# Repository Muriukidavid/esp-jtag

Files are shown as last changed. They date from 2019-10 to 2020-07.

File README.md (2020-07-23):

This is a JTAG programmer for esp targets based on esp-prog redone in Kicad.

The goal of this repo is to enable customization by adding or removing features. Feel welcome to fork the repo and share back your customizations through a pull request.

### Features:
* FT2232H based
* Esp Jtag programming
* A separate serial port for debug
* SN74AH buffers for JTAG IO pins(5V/3V torelant)
* Rx/Tx status LEDs
* Autoprogram using RTS and DTS signals

### TODO
* <s>Layout the PCB and route</s>
- <s>Add LCSC.com BOM column</s> 
* Add digikey BOM column
<br/>

### Schematic
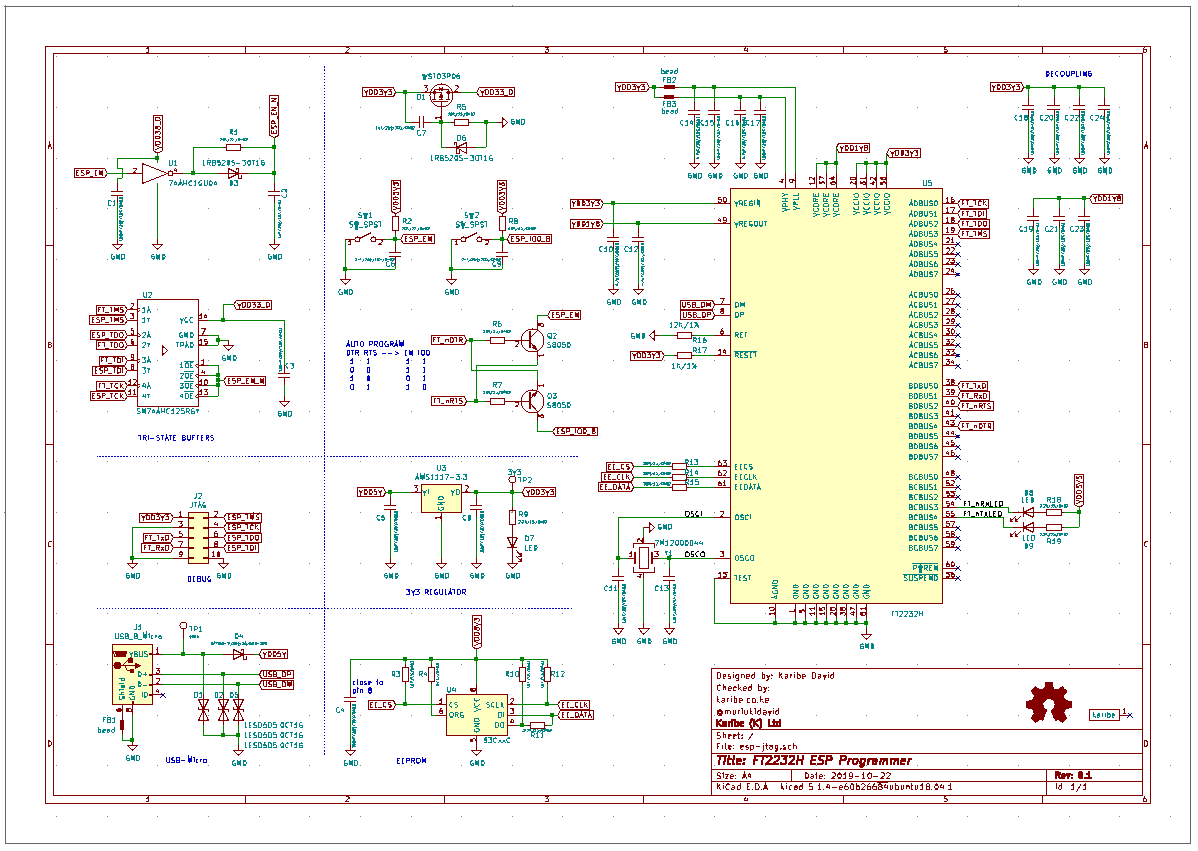
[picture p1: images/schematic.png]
The schematic


### Board 3D Top View 

A preview of the on-going PCB layout design
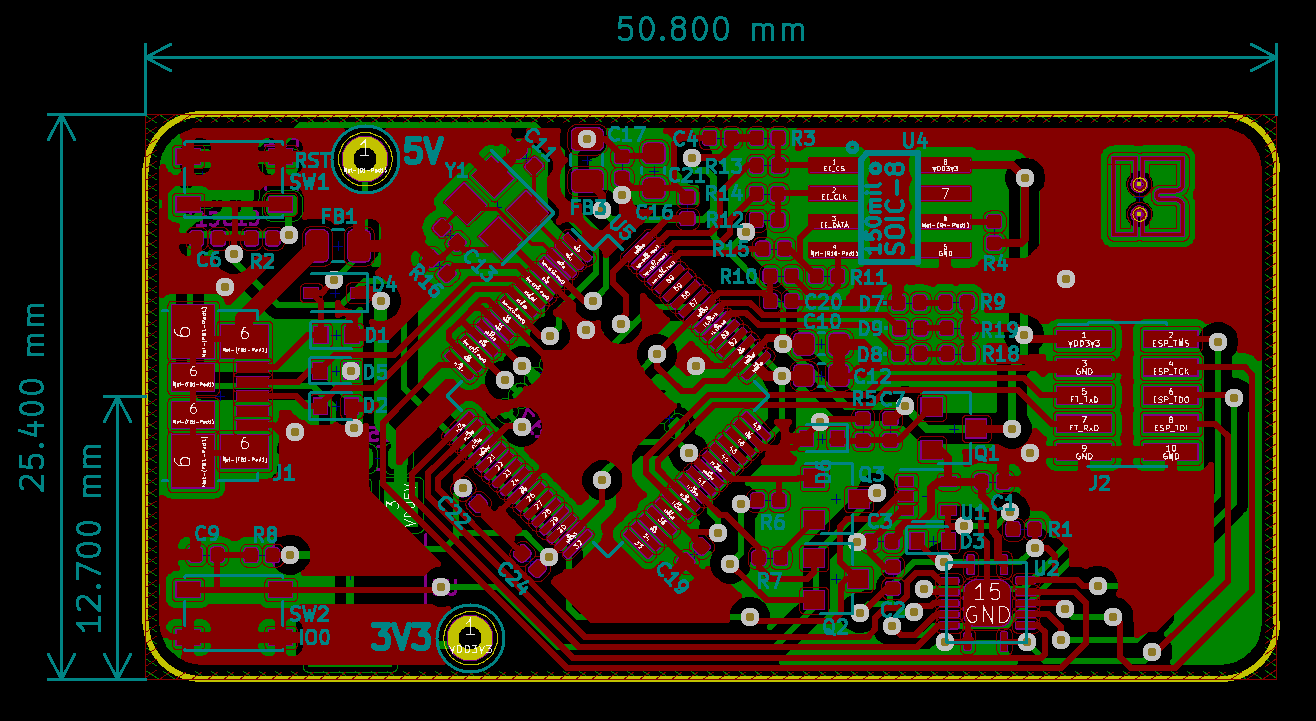
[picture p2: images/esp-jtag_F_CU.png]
Board top copper


3D TOP view 
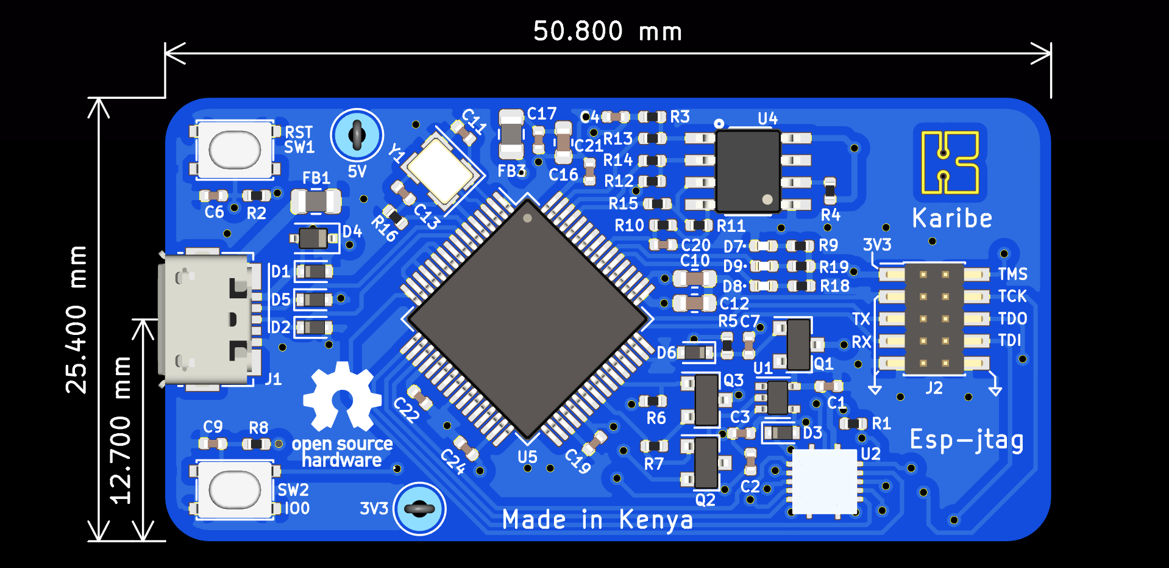
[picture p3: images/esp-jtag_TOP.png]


3D ISO view 
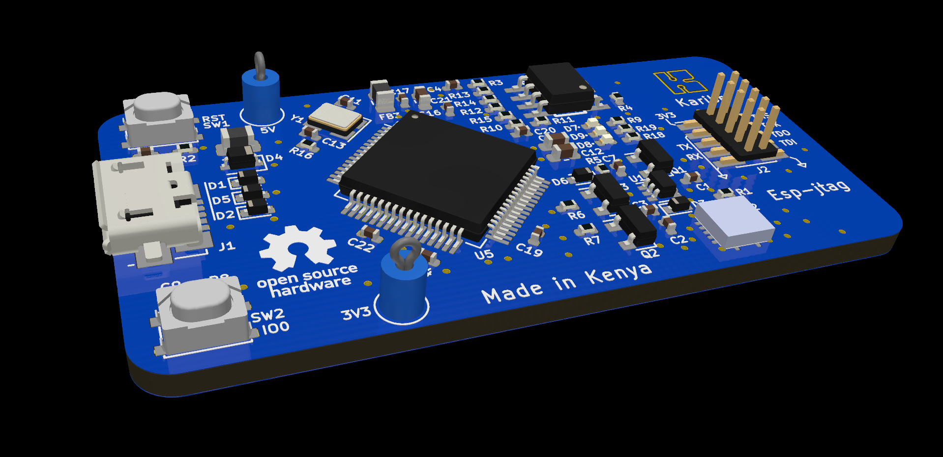
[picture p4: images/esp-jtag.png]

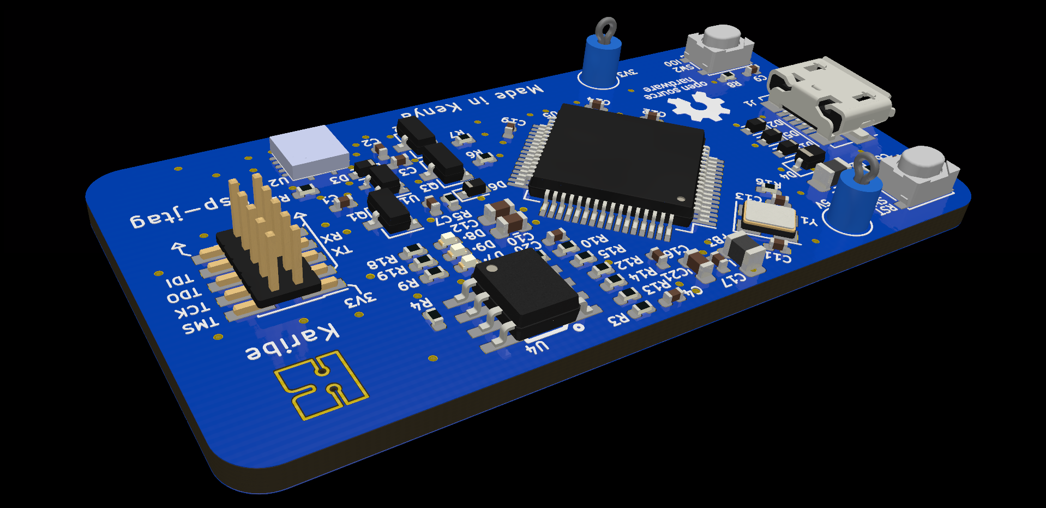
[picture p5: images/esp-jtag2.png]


### BOM
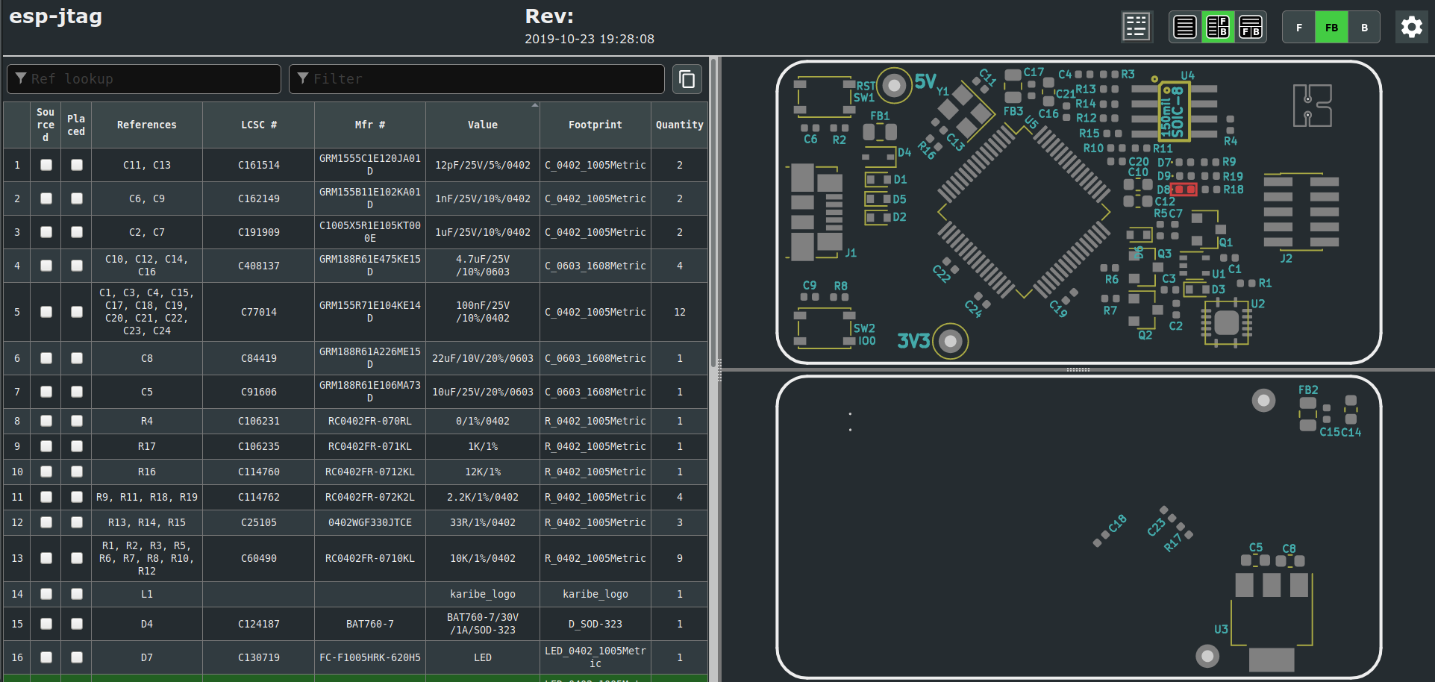
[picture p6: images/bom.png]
BOM
<a href="bom/ibom.html" rel="BOM">

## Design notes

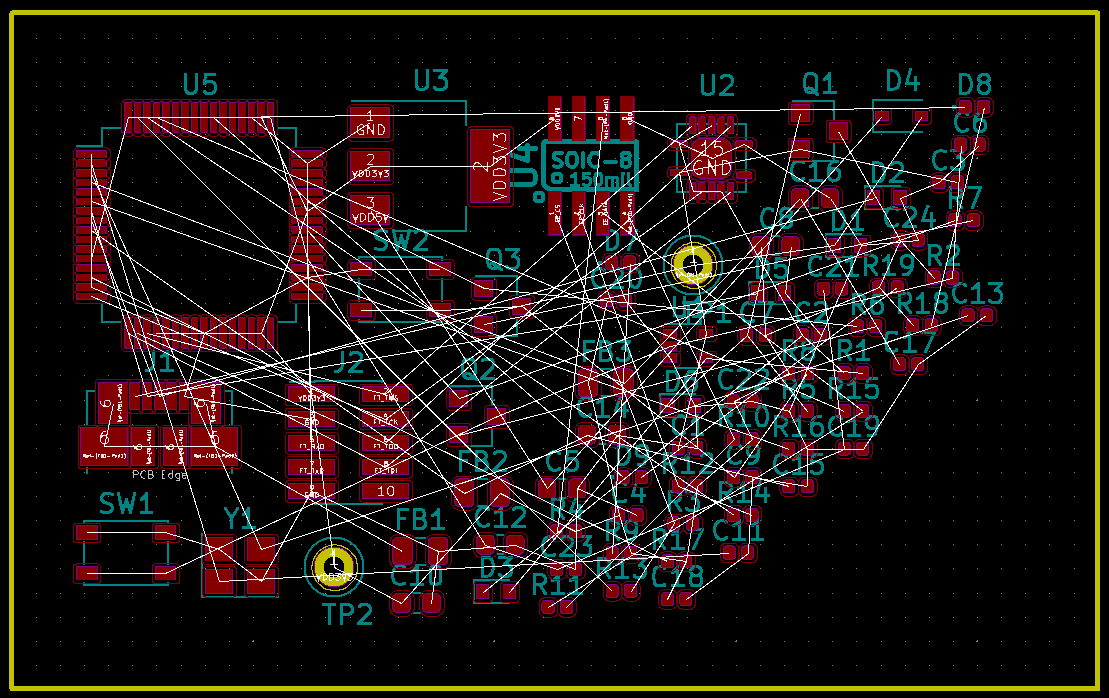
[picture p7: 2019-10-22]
images/layout.png

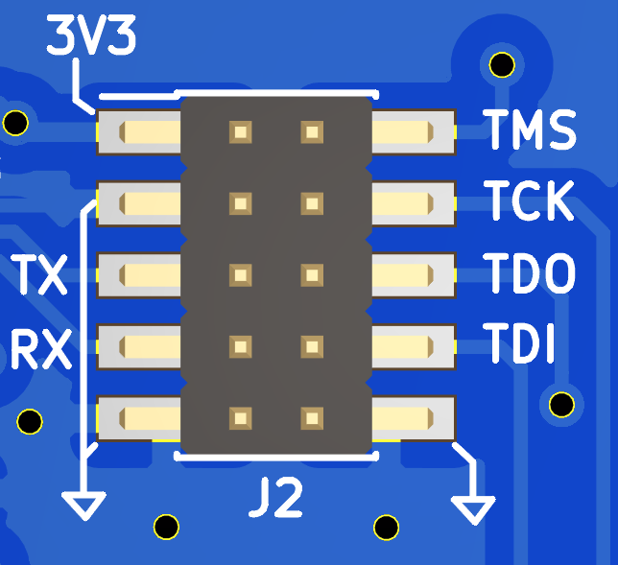
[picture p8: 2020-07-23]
images/jtag_connector.png

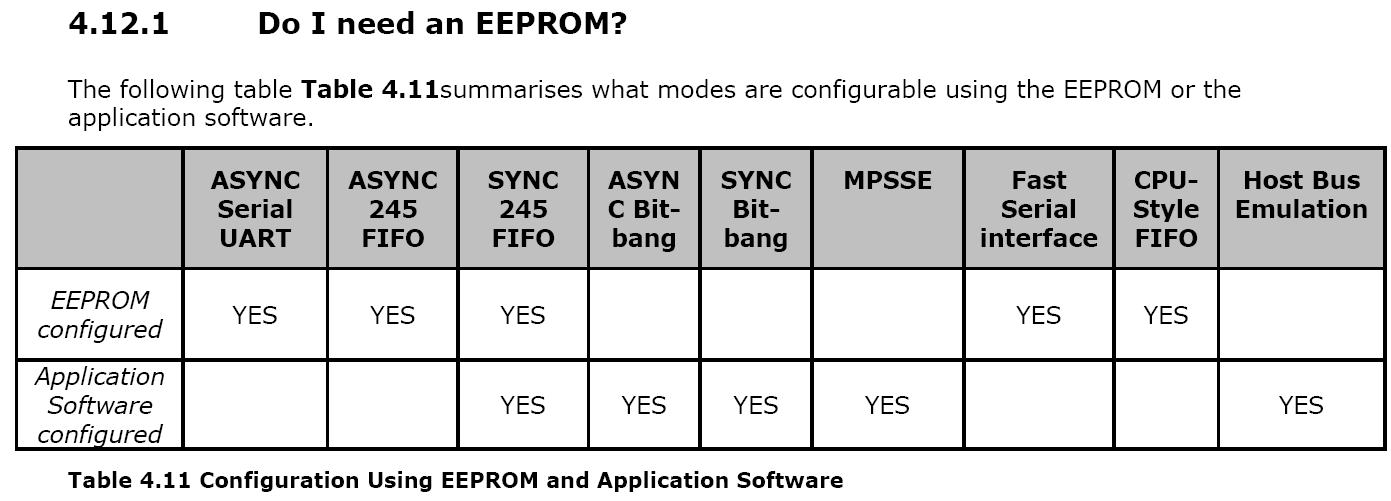
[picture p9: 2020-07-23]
images/ft2232H-eeprom.png

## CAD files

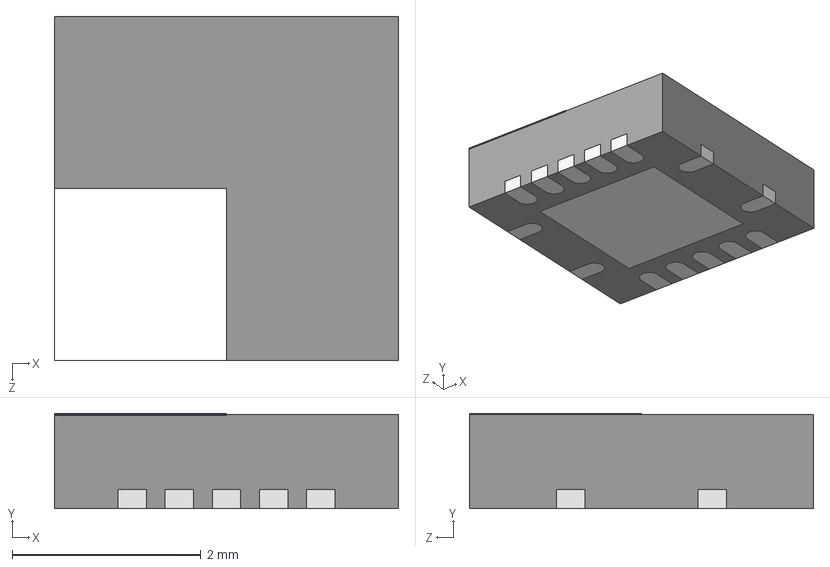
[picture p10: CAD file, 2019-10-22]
3Dmodels/SN74AHC04RGYR.step
3.65 x 1.01 x 3.65 mm

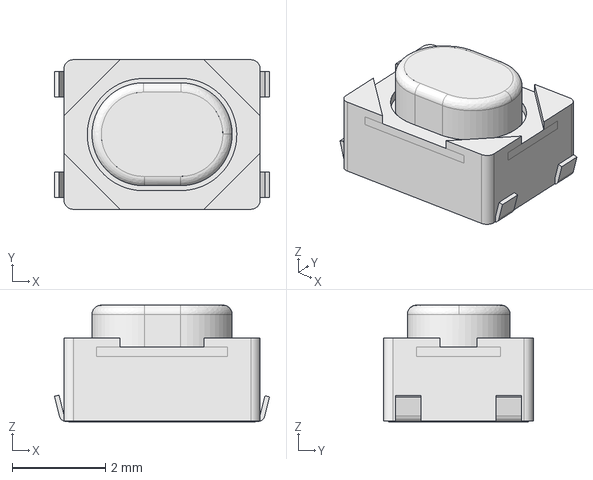
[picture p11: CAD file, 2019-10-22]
3Dmodels/PTS810.step
4.60 x 3.20 x 2.50 mm

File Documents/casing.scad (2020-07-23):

/* 
Parameters 
*/
//Global resolution angle
$fa = .3;
//Global resolution side
$fs = .3;

//Width of the casing
width = 50.8;
//Breadth of the casing
breadth = 25.4;
//Height of the casing
height = 5;
//wall thickness
wallThickness = 2;
//allowance around the inside of the casing
allowance = 0.2;

/* Renders*/
base(width, breadth, height, wallThickness);

/* Modules */
//create outer shell
module base(shellWidth, shellBreadth, shellHeight, shellThickness){
    difference(){
    union(){
    difference(){
        cube([width+2*shellThickness, breadth+2*shellThickness, shellHeight+shellThickness], center = true);
        translate([0,0,(shellThickness/2)+1])
        cube([shellWidth, shellBreadth, shellHeight], center = true);
    }
    translate([shellWidth/2-shellHeight/2,shellBreadth/2-shellHeight/2,shellThickness])
    #cube([shellHeight/2, shellHeight/2,shellHeight], center=true);
    }
    translate([shellWidth/2-shellHeight/2,shellBreadth/2-shellHeight/2,shellThickness])
    cylinder(d=shellHeight, h=shellHeight, center=true);
    }
}

module cover(){
    
}

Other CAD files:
3Dmodels/SN74AHC04RGYR.igs

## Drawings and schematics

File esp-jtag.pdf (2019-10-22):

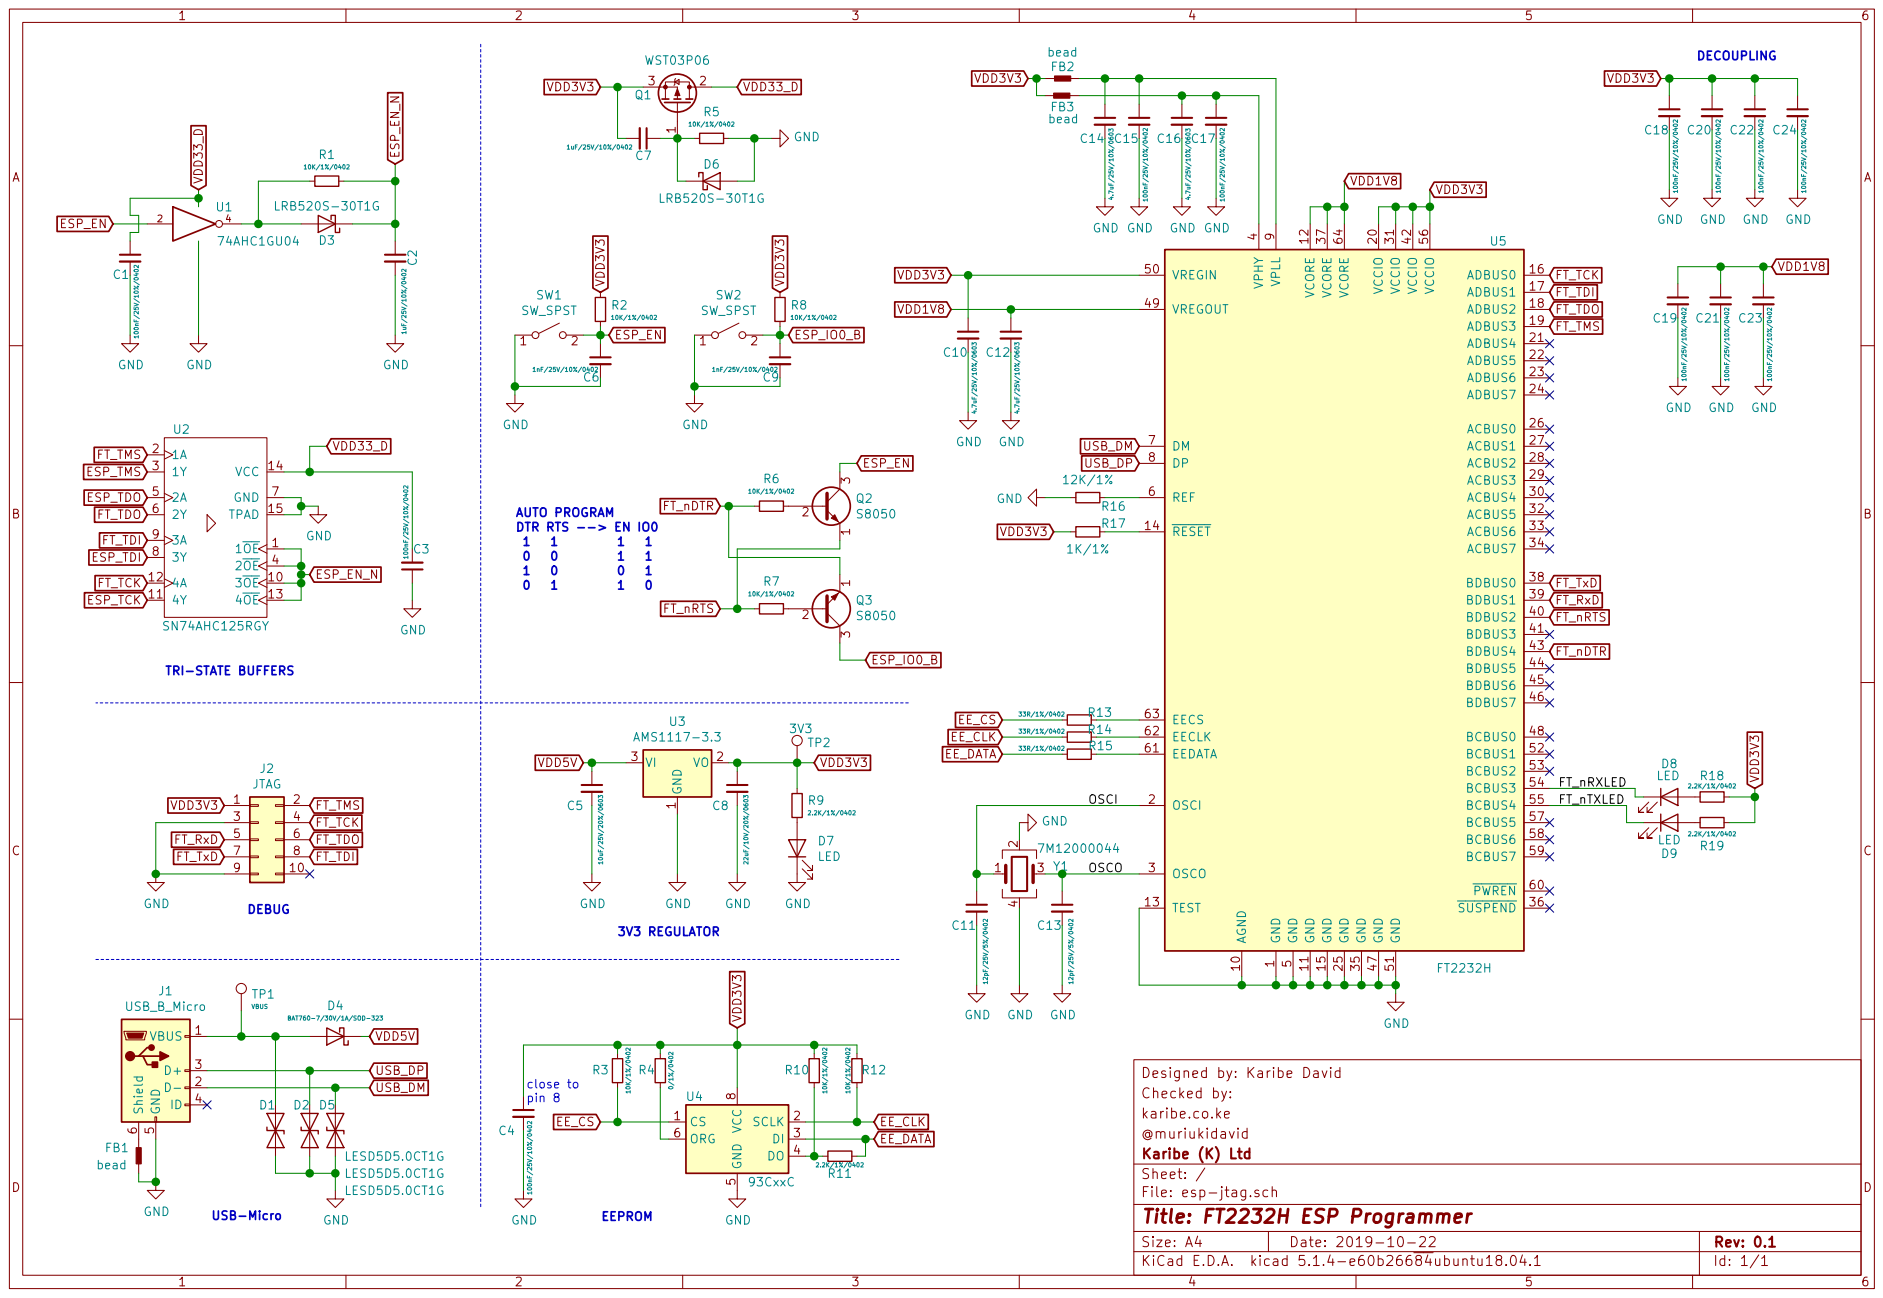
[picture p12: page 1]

1 AGND 10 GND 11 VCORE 12 TEST 13 RESET 14 GND 15 ADBUS0 16 ADBUS1 17 ADBUS2 18 ADBUS3 19 OSCI 2 VCCIO 20 ADBUS4 21 ADBUS5 22 ADBUS6 23 ADBUS7 24 GND 25 ACBUS0 26 ACBUS1 27 ACBUS2 28 ACBUS3 29 OSCO 3 ACBUS4 30 VCCIO 31 ACBUS5 32 ACBUS6 33 ACBUS7 34 GND 35 SUSPEND 36 VCORE 37 BDBUS0 38 BDBUS1 39 VPHY

4 BDBUS2 40 BDBUS3 41 VCCIO 42 BDBUS4 43 BDBUS5 44 BDBUS6 45 BDBUS7 46 GND 47 BCBUS0 48 VREGOUT 49 GND

5 VREGIN 50 GND 51 BCBUS1 52 BCBUS2 53 BCBUS3 54 BCBUS4 55 VCCIO 56 BCBUS5 57 BCBUS6 58 BCBUS7 59 REF 6 PWREN 60 EEDATA 61 EECLK 62 EECS 63 VCORE 64 DM 7 DP 8 VPLL

Designed by: Karibe David
karibe.co.ke Checked by:

@muriukidavid
File: esp-jtag.sch Sheet: / Karibe (K) Ltd

Id: 1/1 Title: FT2232H ESP Programmer

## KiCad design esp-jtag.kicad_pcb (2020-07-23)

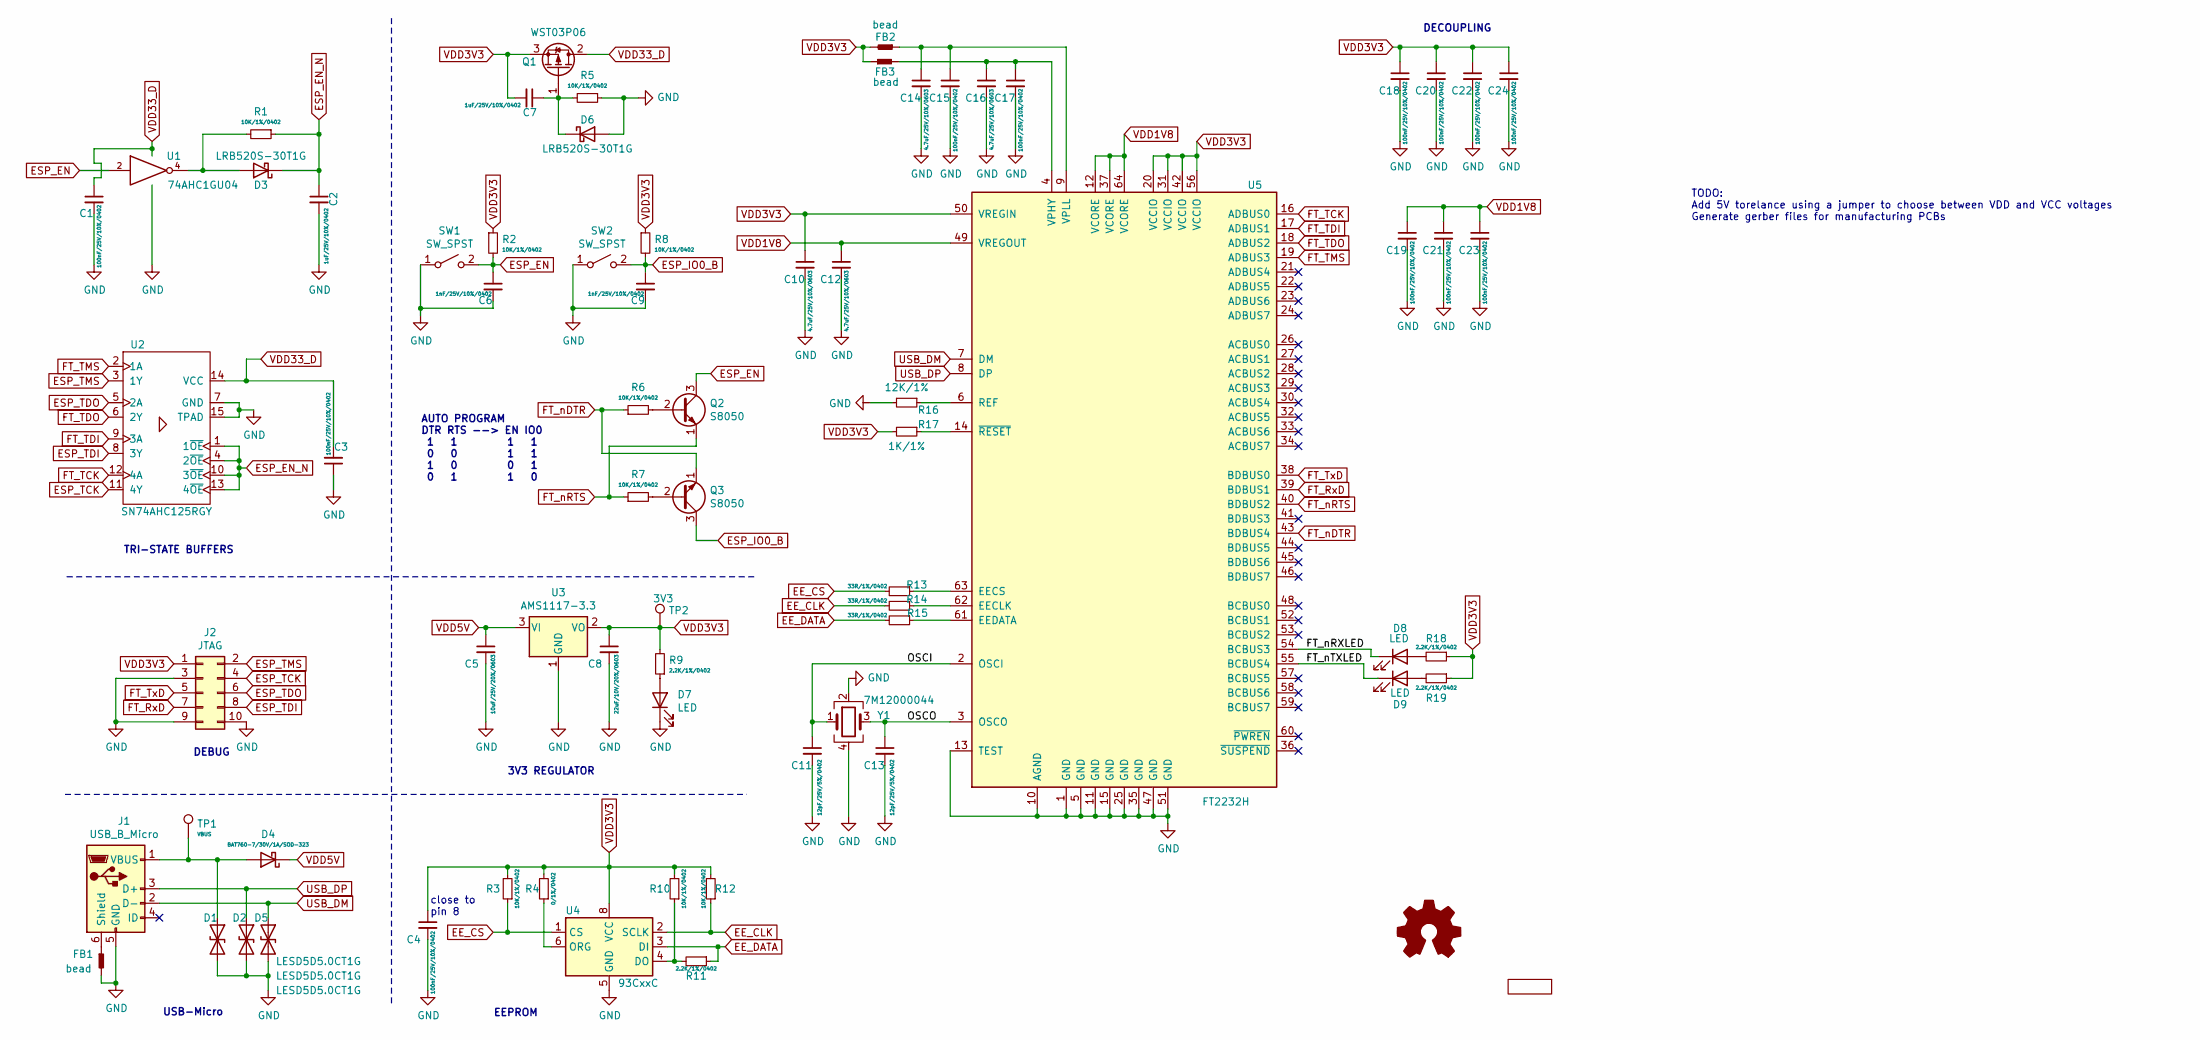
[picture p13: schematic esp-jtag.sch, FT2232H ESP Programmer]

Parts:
C1, C3, C4, C15, C17, C18, C19, C20, C21, C22, C23, C24: 100nF/25V/10%/0402; C_0402_1005Metric; Mfr # GRM155R71E104KE14D; LCSC # C77014
C2, C7: 1uF/25V/10%/0402; C_0402_1005Metric; Mfr # C1005X5R1E105KT000E; LCSC # C191909
C5: 10uF/25V/20%/0603; C_0603_1608Metric; Mfr # GRM188R61E106MA73D; LCSC # C91606
C6, C9: 1nF/25V/10%/0402; C_0402_1005Metric; Mfr # GRM155B11E102KA01D; LCSC # C162149
C8: 22uF/10V/20%/0603; C_0603_1608Metric; Mfr # GRM188R61A226ME15D; LCSC # C84419
C10, C12, C14, C16: 4.7uF/25V/10%/0603; C_0603_1608Metric; Mfr # GRM188R61E475KE15D; LCSC # C408137
C11, C13: 12pF/25V/5%/0402; C_0402_1005Metric; Mfr # GRM1555C1E120JA01D; LCSC # C161514
D1, D2, D5: LESD5D5.0CT1G; D_SOD-523; Mfr # LESD5D5.0CT1G; LCSC # C383211
D3, D6: LRB520S-30T1G; D_SOD-523; Mfr # LRB520S-30T1G; LCSC # C83680
D4: BAT760-7/30V/1A/SOD-323; D_SOD-323; Mfr # BAT760-7; LCSC # C124187
D7: LED; LED_0402_1005Metric; Mfr # FC-F1005HRK-620H5; LCSC # C130719
D8: LED; LED_0402_1005Metric; Mfr # BL-HB337A-AV-TRB; LCSC # C165977
D9: LED; LED_0402_1005Metric; Mfr # BL-HGE37A-AV-TRB; LCSC # C165979
FB1, FB2, FB3: bead; L_0805_2012Metric; Mfr # BLM21AG601SN1D; LCSC # C85837
J1: USB_B_Micro; USB_Micro-B_Molex_47346-0001; Mfr # 47346-0001; LCSC # C132560
J2: JTAG; PinHeader_2x05_P1.27mm_Vertical_SMD
L1: karibe_logo
Q1: WST03P06; SOT-23; Mfr # WST03P06; LCSC # C105166
Q2, Q3: S8050; SOT-23; Mfr # S8050; LCSC # C2146
R1, R2, R3, R5, R6, R7, R8, R10, R12: 10K/1%/0402; R_0402_1005Metric; Mfr # RC0402FR-0710KL; LCSC # C60490
R4: 0/1%/0402; R_0402_1005Metric; Mfr # RC0402FR-070RL; LCSC # C106231
R9, R11, R18, R19: 2.2K/1%/0402; R_0402_1005Metric; Mfr # RC0402FR-072K2L; LCSC # C114762
R13, R14, R15: 33R/1%/0402; R_0402_1005Metric; Mfr # 0402WGF330JTCE; LCSC # C25105
R16: 12K/1%; R_0402_1005Metric; Mfr # RC0402FR-0712KL; LCSC # C114760
R17: 1K/1%; R_0402_1005Metric; Mfr # RC0402FR-071KL; LCSC # C106235
SW1, SW2: SW_SPST; SW_SPST_PTS810; Mfr # PTS810SJG250SMTRLFS; LCSC # C221895
TP1: VBUS; TestPoint_Loop_D1.80mm_Drill1.0mm_Beaded; Mfr # 5001; LCSC # C238122
TP2: 3V3; TestPoint_Loop_D1.80mm_Drill1.0mm_Beaded; Mfr # 5001; LCSC # C238122
U1: 74AHC1GU04; SOT-353_SC-70-5; Mfr # 74AHC1GU04GW,125; LCSC # C5514
U2: SN74AHC125RGY; VQFN-14_3.6x3.6x05P; Mfr # SN74AHC125RGY; LCSC # C181604
U3: AMS1117-3.3; SOT-223-3_TabPin2; Mfr # AMS1117-3.3; LCSC # C6186
U4: 93CxxC; SOIC-8_150mil; Mfr # M93C46-WMN6TP; LCSC # C7565
U5: FT2232H; LQFP-64_10x10mm_P0.5mm; Mfr # FT2232HL-REEL; LCSC # C27882
Y1: 7M12000044; Crystal_SMD_3225-4Pin_3.2x2.5mm; Mfr # 7M12000044; LCSC # C93114

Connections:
/FT_nRXLED: D8.1 (K), U5.54 (BCBUS3)
/FT_nTXLED: D9.1 (K), U5.55 (BCBUS4)
/OSCI: C11.1, U5.2 (OSCI), Y1.1
/OSCO: C13.1, U5.3 (OSCO), Y1.3
EE_CLK: R12.1, R14.2, U4.2 (SCLK)
EE_CS: R3.1, R13.2, U4.1 (CS)
EE_DATA: R11.1, R15.2, U4.3 (DI)
ESP_EN: C6.1, Q2.3 (C), R2.2, SW1.2 (B), U1.2
ESP_EN_N: C2.1, D3.1 (K), R1.1, U2.1 (1~OE), U2.4 (2~OE), U2.10 (3~OE), U2.13 (4~OE)
ESP_IO0_B: C9.1, Q3.3 (C), R8.2, SW2.2 (B)
ESP_TCK: J2.4, U2.11 (4Y)
ESP_TDI: J2.8, U2.8 (3Y)
ESP_TDO: J2.6, U2.5 (2A)
ESP_TMS: J2.2, U2.3 (1Y)
FT_RxD: J2.7, U5.39 (BDBUS1)
FT_TCK: U2.12 (4A), U5.16 (ADBUS0)
FT_TDI: U2.9 (3A), U5.17 (ADBUS1)
FT_TDO: U2.6 (2Y), U5.18 (ADBUS2)
FT_TMS: U2.2 (1A), U5.19 (ADBUS3)
FT_TxD: J2.5, U5.38 (BDBUS0)
FT_nDTR: Q3.1 (E), R6.1, U5.43 (BDBUS4)
FT_nRTS: Q2.1 (E), R7.1, U5.40 (BDBUS2)
GND: C1.2, C2.2, C3.1, C4.2, C5.2, C6.2, C8.2, C9.2, C10.2, C11.2, C12.2, C13.2, C14.2, C15.2, C16.2, C17.2, C18.2, C19.2, C20.2, C21.2, C22.2, C23.2, C24.2, D1.2 (A2), D2.2 (A2), D5.2 (A2), D6.2 (A), D7.1 (K), FB1.2, J1.5 (GND), J2.3, J2.9, J2.10, R5.1, R16.2, SW1.1 (A), SW2.1 (A), U1.3 (GND), U2.7 (GND), U2.15 (TPAD), U3.1 (GND), U4.5 (GND), U5.1 (GND), U5.5 (GND), U5.10 (AGND), U5.11 (GND), U5.13 (TEST), U5.15 (GND), U5.25 (GND), U5.35 (GND), U5.47 (GND), U5.51 (GND), Y1.2, Y1.4
unnamed: C7.1, D6.1 (K), Q1.1 (G), R5.2
unnamed: C14.1, C15.1, FB2.1, U5.9 (VPLL)
unnamed: C16.1, C17.1, FB3.2, U5.4 (VPHY)
unnamed: D1.1 (A1), D4.2 (A), J1.1 (VBUS), TP1.1
unnamed: D3.2 (A), R1.2, U1.4
unnamed: D7.2 (A), R9.1
unnamed: D8.2 (A), R18.2
unnamed: D9.2 (A), R19.2
unnamed: FB1.1, J1.6 (Shield)
unnamed: Q2.2 (B), R6.2
unnamed: Q3.2 (B), R7.2
unnamed: R4.1, U4.6 (ORG)
unnamed: R10.1, R11.2, U4.4 (DO)
unnamed: R13.1, U5.63 (EECS)
unnamed: R14.1, U5.62 (EECLK)
unnamed: R15.1, U5.61 (EEDATA)
unnamed: R16.1, U5.6 (REF)
unnamed: R17.1, U5.14 (~RESET)
USB_DM: D5.1 (A1), J1.2 (D-), U5.7 (DM)
USB_DP: D2.1 (A1), J1.3 (D+), U5.8 (DP)
VDD1V8: C12.1, C19.1, C21.1, C23.1, U5.12 (VCORE), U5.37 (VCORE), U5.49 (VREGOUT), U5.64 (VCORE)
VDD3V3: C4.1, C7.2, C8.1, C10.1, C18.1, C20.1, C22.1, C24.1, FB2.2, FB3.1, J2.1, Q1.3 (S), R2.1, R3.2, R4.2, R8.1, R9.2, R10.2, R12.2, R17.2, R18.1, R19.1, TP2.1, U3.2 (VO), U4.8 (VCC), U5.20 (VCCIO), U5.31 (VCCIO), U5.42 (VCCIO), U5.50 (VREGIN), U5.56 (VCCIO)
VDD5V: C5.1, D4.1 (K), U3.3 (VI)
VDD33_D: C1.1, C3.2, Q1.2 (D), U1.5 (VCC), U2.14 (VCC)

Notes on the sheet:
close to pin 8
EEPROM
USB-Micro
3V3 REGULATOR
DECOUPLING
DEBUG
TRI-STATE BUFFERS
AUTO PROGRAM DTR RTS --> EN IO0 1 1 1 1 0 0 1 1 1 0 0 1 0 1 1 0
TODO: Add 5V torelance using a jumper to choose between VDD and VCC voltages Generate gerber files for manufacturing PCBs

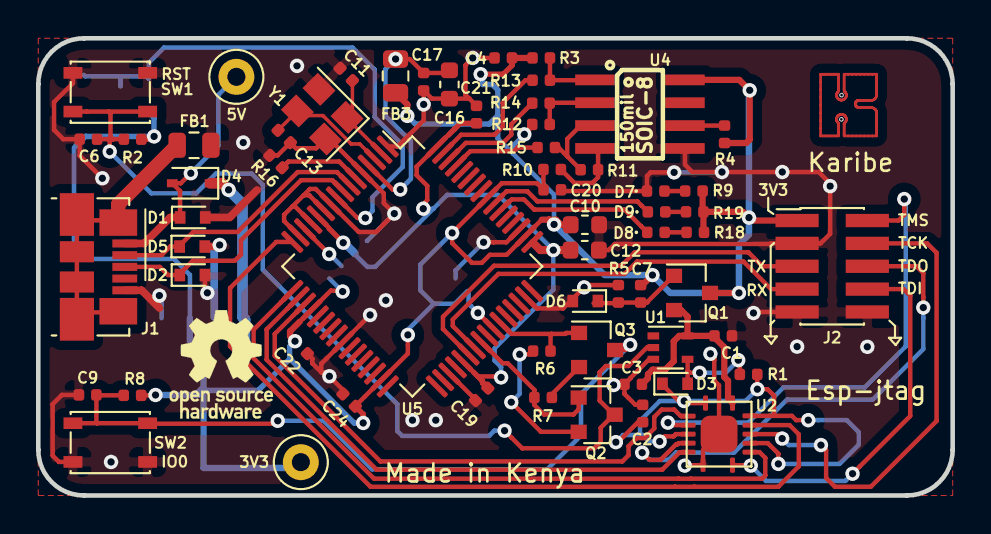
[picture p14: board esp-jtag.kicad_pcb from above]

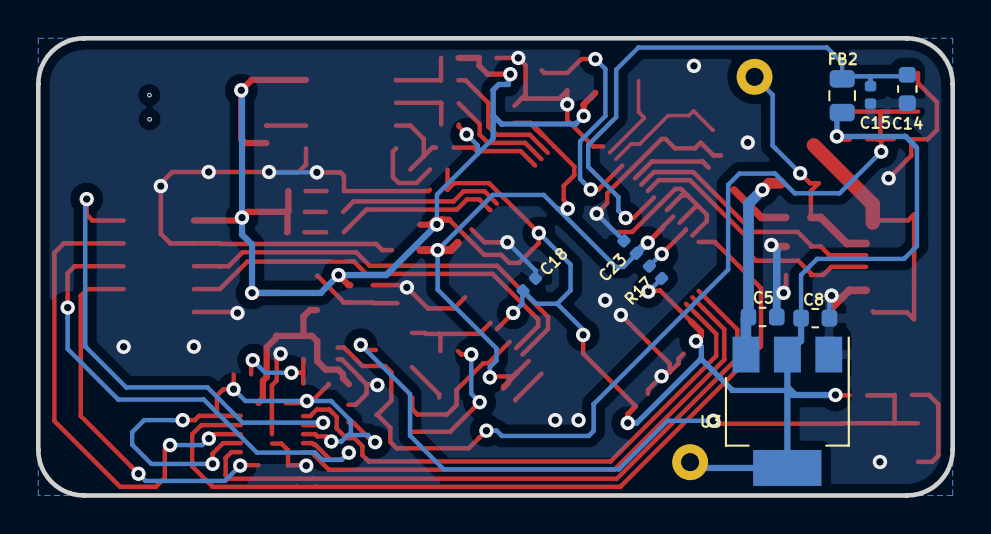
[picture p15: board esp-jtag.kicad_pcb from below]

Board: 2 copper layers, 50.8 x 25.4 mm, 71 parts (9 on the bottom side), 47 nets.

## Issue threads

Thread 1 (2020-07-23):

SPI Flash

pineappletikka, 2020-07-23:
Hi,
I was wondering where is the content of the SPIFlash how to to compile it.
Thanks

Muriukidavid, 2020-07-23:
Hi @pineappletikka thanks for your interest in this, I have not even built this board. The external memory is for storing configurations in order for the FT2232H to be set to operate in different modes, as far as I know. As to how to write to it, I haven't looked into it. I will update these details when I make this board.

Muriukidavid, 2020-07-23:
In case you need more information, check the [datasheet](datasheet https://www.ftdichip.com/Support/Documents/DataSheets/ICs/DS_FT2232H.pdf) page 46.

Muriukidavid, 2020-07-23:
The [FT_Prog](https://www.ftdichip.com/Support/Utilities.htm#FT_PROG) utility is used to write to the external memory

pineappletikka, 2020-07-24:
Hi @Muriukidavid, thanks for the prompt reply!
I will definitely have a look at those documentations.
Good luck with the manufacturing and keep us up to date! :)

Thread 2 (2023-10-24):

Q2 and Q3 (S8050) base and emitter flipped

kJoba, 2023-10-24:
The transistors Q2 and Q3 https://datasheet.lcsc.com/lcsc/1810161230_Jiangsu-Changjing-Electronics-Technology-Co---Ltd--S8050-J3Y_C2146.pdf have their base on pin 1 and emitter on pin2. This seems to be flipped in the schematic.
As a result the automatic toggling of RST and GPIO0 for UART flashing of firmware won't work correctly.

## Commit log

2019-10-22 Add initial revision
    Create a kicad project for the programmer
    Capture a schematic based on esp-prog schematic
    Add manufacturer part number and LCSC part number to all components in the schematic
    Associate all components with correct(hopefully) footprints
    Add missing/custom footprints and 3D models
    export a HTML BOM
    Create initial PCB layout with edge cut polygon and load all the components
    Add a README for the repo
    Add a Documents folder with esp-prog schematic PDF
    Export some images into the images folder, link them in the README
    [PTS810.step, SN74AHC04RGYR.igs, SN74AHC04RGYR.step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]
2019-10-23 Layout and route the PCB
    Prepare the PCB layout by arranging the components
    Route all traces and rectify mistakes in the connections
    Add ground pours on top and bottom copper
    Update the preview images and the README file
    [esp-jtag.kicad_pcb, esp-jtag.sch]
2020-07-23 Minor tweaks
    Finalize PCB layout, especially top silkscreen
    Export ray-tracing renders
    Update the README file
    [casing.scad, esp-jtag.kicad_pcb, esp-jtag.sch]
